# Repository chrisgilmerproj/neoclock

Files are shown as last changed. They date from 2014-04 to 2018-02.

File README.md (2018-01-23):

NeoClock
========

Neopixel clock based on neopixel rings from Adafruit.

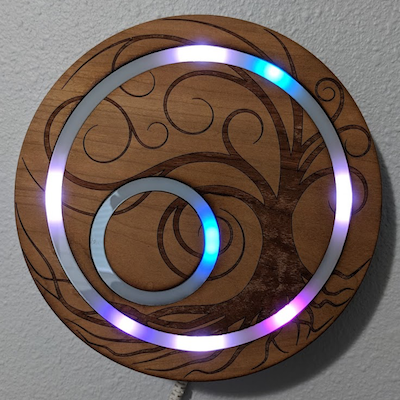
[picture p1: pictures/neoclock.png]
NeoClock


Code
---

The code can be found in the `./code/neoclock/neoclock.ino` file.

This project relies on code from several authors:

- https://github.com/adafruit/Adafruit_NeoPixel
- https://github.com/zeroeth/time_loop
- https://github.com/sparkfun/DeadOn_RTC

Some of the code is copied directly and some is only slightly modified.
Credit is due to the original authors who put in the work that allowed
me to build the clock.  Examples of code used are in the
`./code/examples/` directory.

Usage
---

The clock has two buttons for operation.  These are the Mode button and the
Set button.  The Mode button lets you choose between these choices:

1. Set Hour
2. Set Minute
3. Set Second
4. Set Color Scheme

The clock stops time while you set it allowing you to specify exactly the time
you want.  Finally you can choose one of four pre-programmed color sets for
the different hands of the clock.

Animations
---

Every fifteen minutes there is an animation sequence.  The top of the hour
runs a rainbow cycle.  The other three animations cycle one color through
all the pixels in the clock (Red, Green, Blue).

Laser Cut Files
---

The files used to laser cut the body of the clock are found in the `ponoko`
directory.  The final files sent to Ponoko were:

- `neoclock_ponoko_wood_final.eps`
- `neoclock_ponoko_acrylic_final.eps`

The original SVG files are provided for convenience.

The wood used was a `Veneer MDF Cherry 5.7mm` at 384mm square.

The acrylic used was an `Acrylic Opal 5.6mm` at 181mm square.

Electronics
---

The list of parts can be found in the `electronics` directory.

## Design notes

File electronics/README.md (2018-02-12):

# Electronics

This is a (mostly) complete list of parts used to make the electronics for the clock:

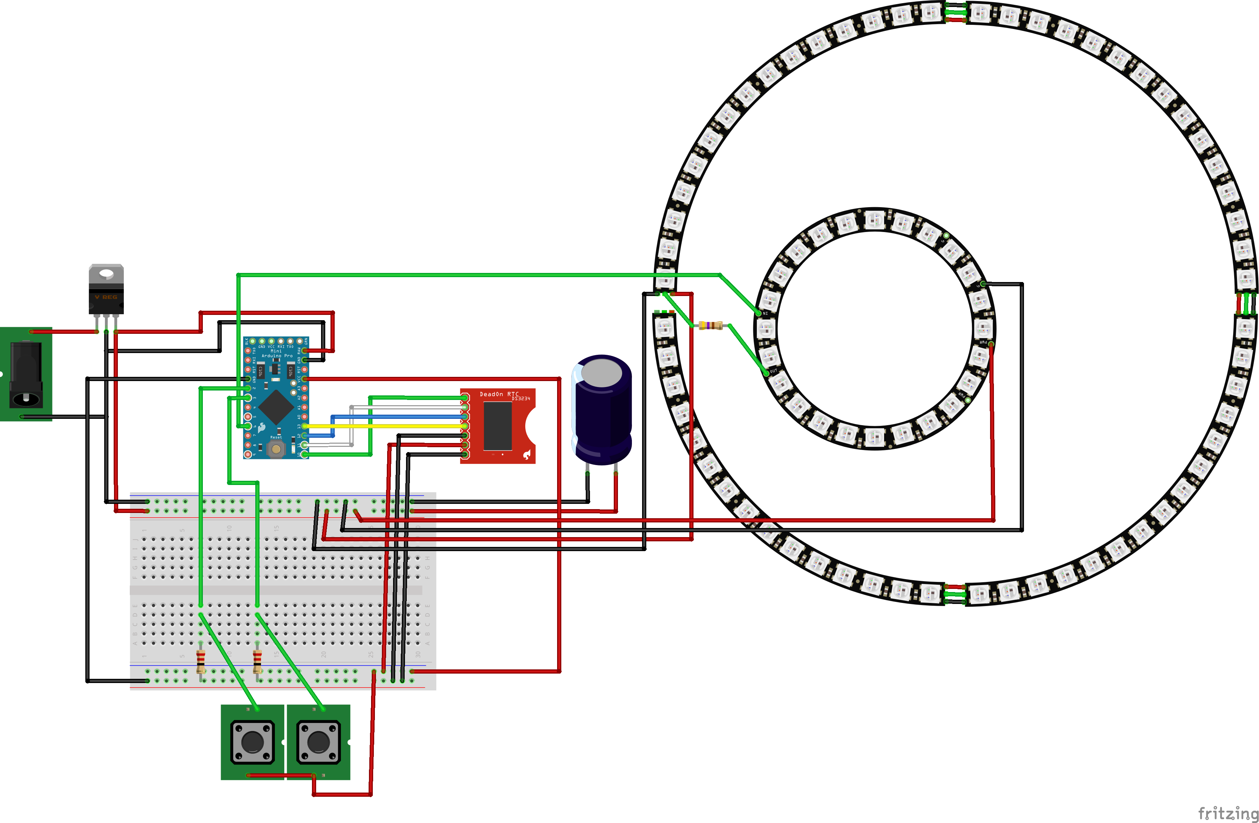
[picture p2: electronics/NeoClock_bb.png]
NeoClock


You can also open the [NeoClock Fritzing File](./NeoClock.fzz) to see how it was set up.

## SparkFun Parts

- 1x [DeadOn RTC Breakout - DS3234](https://www.sparkfun.com/products/10160) (BOB-10160)
- 1x [Coin Cell Battery 12mm CR1225](https://www.sparkfun.com/products/337) (PRT-00337)
- 1x [Arduino Mini 328 - 5V/16MHz](https://www.sparkfun.com/products/11113) (DEV-11113)
- 1x [L7805 Voltage Regulator 5V 1.5A-Max](https://www.sparkfun.com/products/107) (COM-00107)
- Resistors Avalable in [Resistor Kit 1/4W 500 Total](https://www.sparkfun.com/products/10969) (COM-10960)
  - 1x 470 Ohm 1/4W Resistor (yellow, violet, brown, silver)
  - 2x 1 kOhm 1/4W Resistor (brown, black, red, gold) (doesn't have to be exact here, just small and not smaller than)
    - I used 2.21 Ohm 1/4W Resistor (red, red, brown, silver, gold) because I had it, but it is too small

Also needed for programming the Arduino:

- 1x [FTDI Cable 5V](https://www.sparkfun.com/products/9718) (DEV-09718)

Also some wire:

- 1x [Hook-Up Wire - Assortment](https://www.sparkfun.com/products/11367) (Solid Core, 22 AWG ROHS) (PRT-11367)
  - This project used Red, Black and Green primarily.  Secondary colors are Yellow, Blue, White.

## Adafruit Parts

- 1x [NeoPixel Ring - 24 x WS2812 5050 RGB LED with Integrated Drivers](https://www.adafruit.com/product/1586) (1586)
- 4x [NeoPixel 1/4 60 Ring - 5050 RGB LED w/ Integrated Drivers](https://www.adafruit.com/product/1768) (1768)

## Radio Shack Parts

- 12V 1.5A Power Supply (Amperage is important here! Probably needs a min of 1A)
- 1x [1000uF Electrolytic Capacitor](https://www.radioshack.com/products/radioshack-1000uf-35v-20-axial-lead-electrolytic-capacitor) (Axial Leads, 35WVDC max) (272-1019)
- 2x [SPST Momentary Pushbutton Switch](https://www.radioshack.com/products/spst-pushbtn-swch) Contacts (N.O.) rated 3A at 125VAC or 1.5A at 250VAC (275-0644)
- 1x [Size K Coaxial DC Power Jack with Switch](https://www.radioshack.com/products/radioshack-size-k-coaxial-dc-power-jack-w-switch) (N.C. break circuit, 5.0mm OD, 2.1mm ID, with mounting hardware) (274-1565)
- 1x Mixed Round circuit boards
  - 1x 30mm in diameter
  - 1x 25mm in diameter
  - 1x 15mm in diameter

## Home Depot Parts

- 1x [Super Magnets, 12 Neodymium Ring Magnets](https://www.homedepot.com/p/MASTER-MAGNETICS-3-8-in-Neodymium-Rare-Earth-Magnet-Discs-12-per-Pack-07090HD/202526371) (095421070909)
- 1x [Gorilla Wood Glue](https://www.homedepot.com/p/Gorilla-8-fl-oz-Wood-Glue-62000/100672167) (052427620002)
- 1x [3/8 in x 4 ft wood round dowel](https://www.homedepot.com/p/3-8-in-x-48-in-Wood-Round-Dowel-HDDH3848/204354371)

## Other Parts

- Heat Shrink Tubing
- Quick Disconnects for wires

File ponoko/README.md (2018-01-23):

# Ponoko Files

These files were used to laser cut the clock body.  Here is a preview of the file:

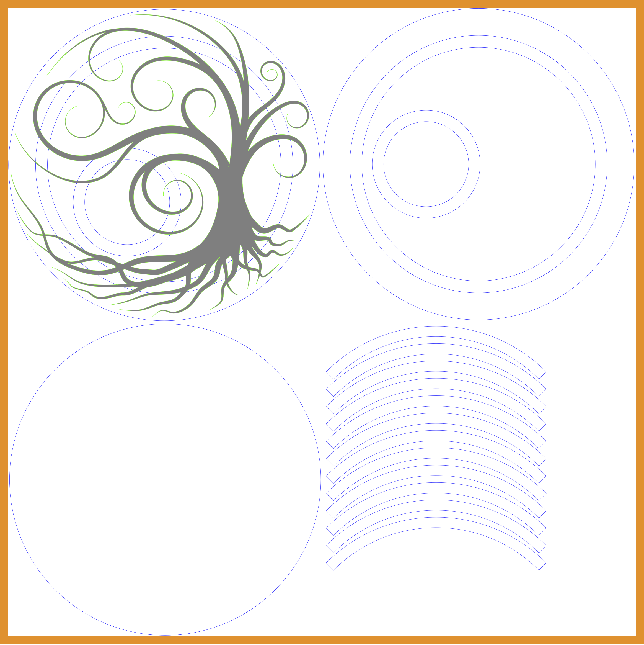
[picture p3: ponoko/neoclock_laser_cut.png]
NeoClock Body


**NOTE:** Only the `*.eps` files were sent to Ponoko.

All files were created using [Inkscape](https://inkscape.org/en/).

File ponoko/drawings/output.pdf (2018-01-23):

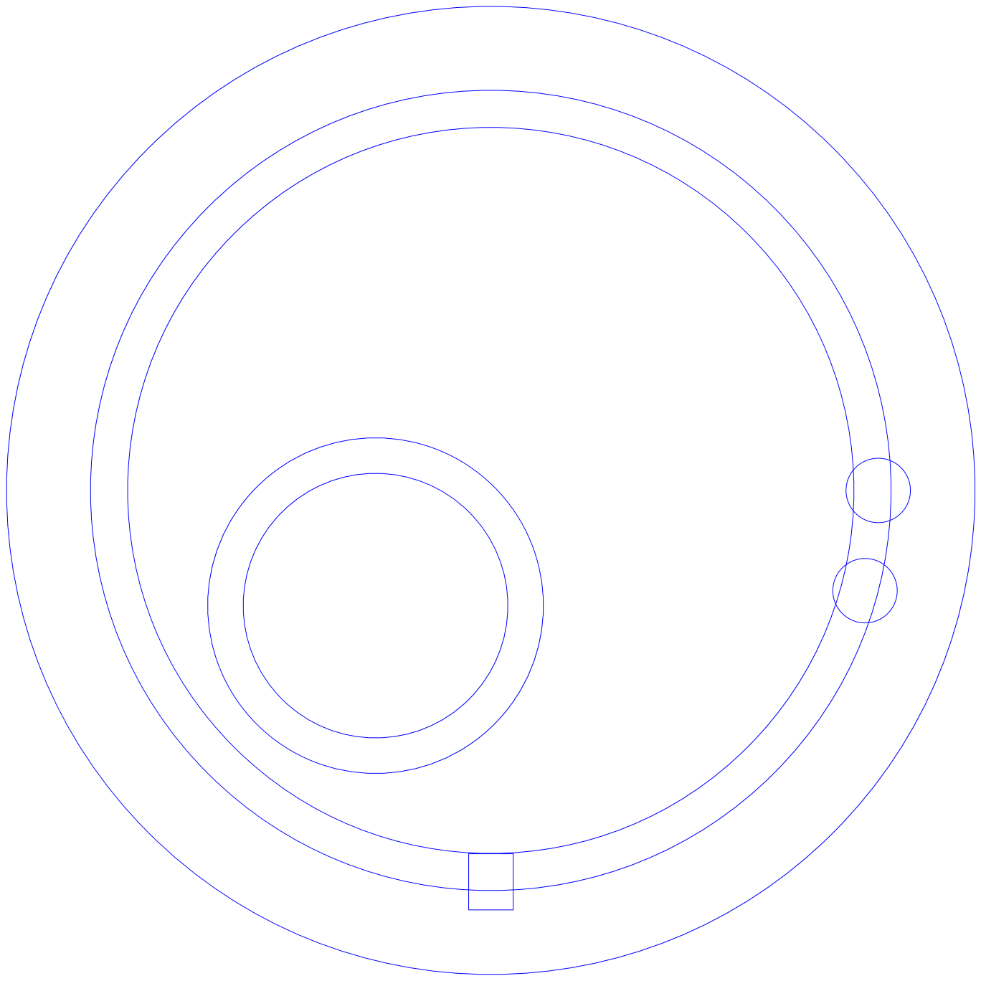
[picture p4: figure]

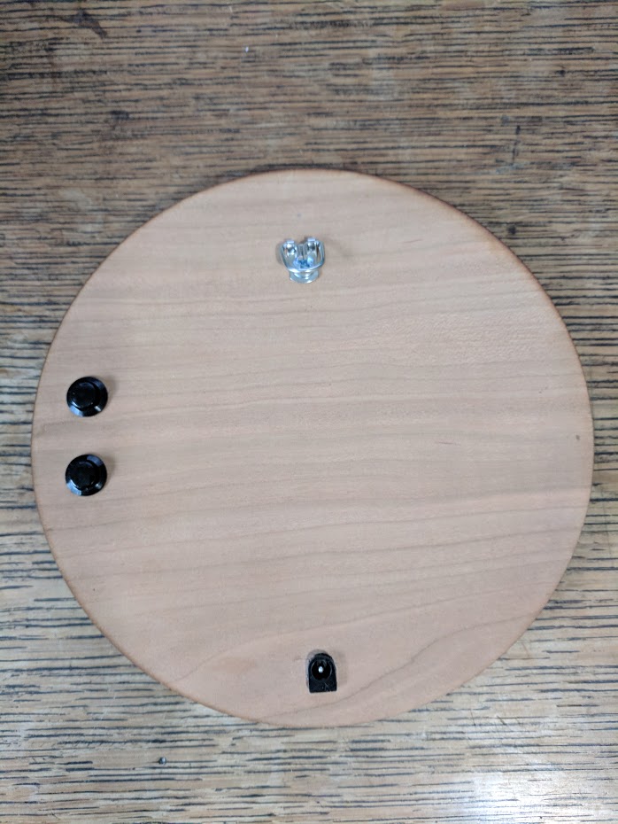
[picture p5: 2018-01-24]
pictures/neoclock_back.jpg

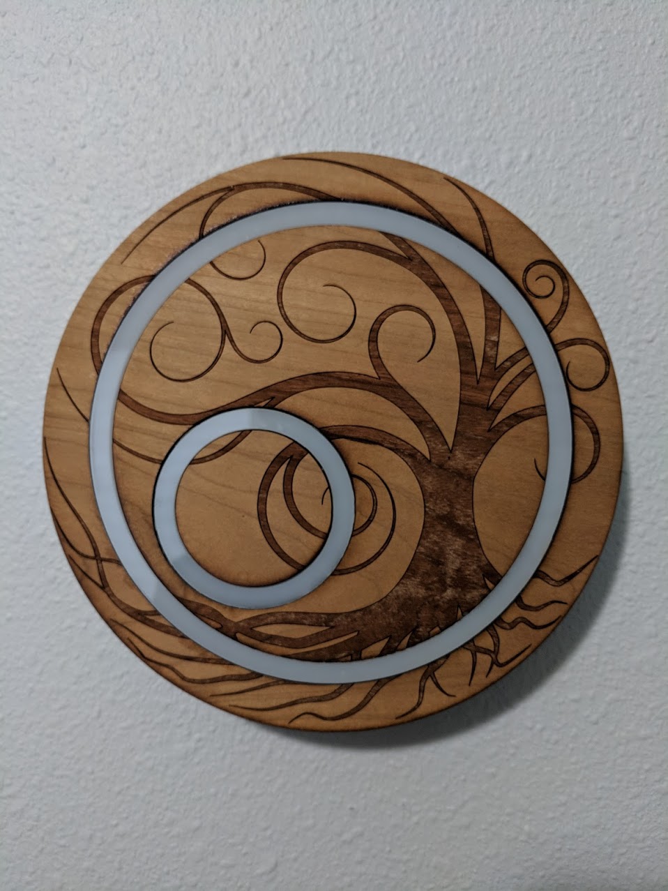
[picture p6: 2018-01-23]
pictures/neoclock_off.jpg

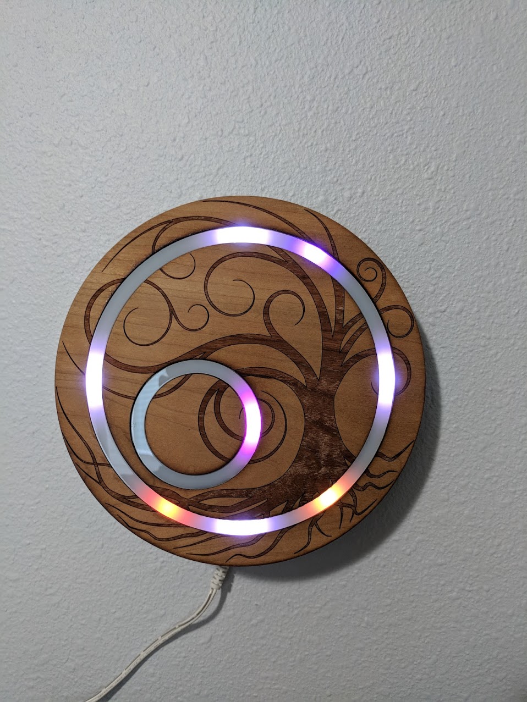
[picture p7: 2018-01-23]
pictures/neoclock_color_scheme_2.jpg

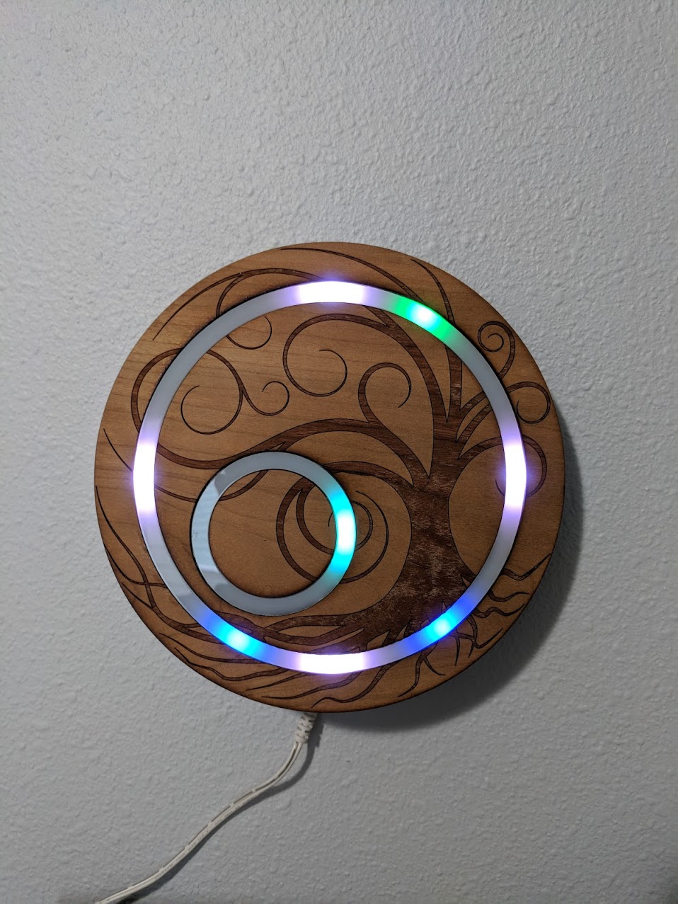
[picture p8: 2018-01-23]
pictures/neoclock_color_scheme_3.jpg

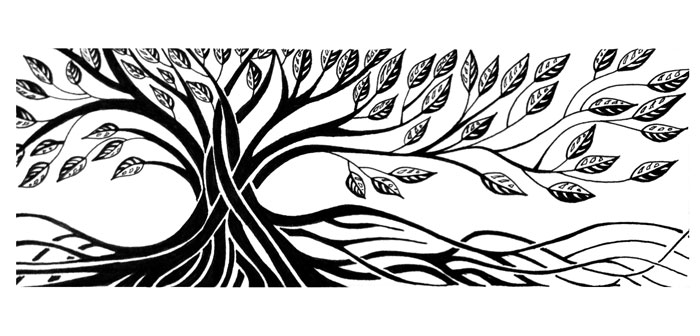
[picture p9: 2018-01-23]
ponoko/tree_research/zana_tree-of-life.jpg

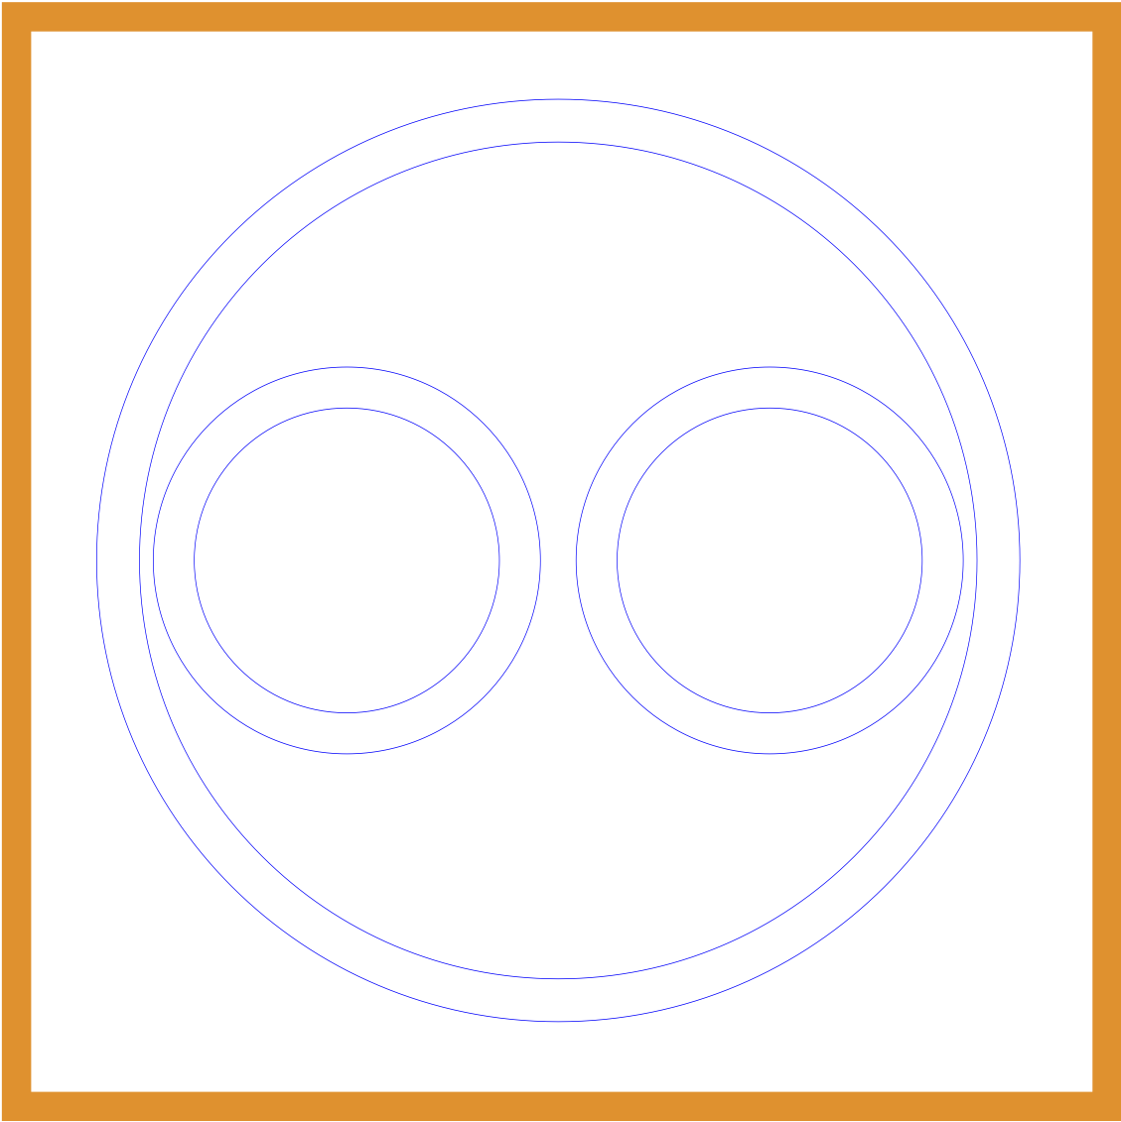
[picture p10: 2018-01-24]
ponoko/neoclock_laser_cut_acrylic.png

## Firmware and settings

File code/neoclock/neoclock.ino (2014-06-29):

// modified  https://github.com/zeroeth/time_loop
// modified  https://github.com/sparkfun/DeadOn_RTC
#include <Adafruit_NeoPixel.h>
#include <SPI.h>

#define SET_CLOCK_PIN 2
#define SET_TIME_PIN 3
#define RING_PIN 6
#define SLAVE_SELECT 10 // slave select rtc

// Set Clock Button
int clock_state;
int last_clock_state = LOW;

// Set Time Button
int time_state;
int last_time_state = LOW;

// Track Clock Set States
int num_states = 5;       // Number of clock states:
int clock_time_state = 0; // 0 - Run Clock
                          // 1 - Set Hour
                          // 2 - Set Minute
                          // 3 - Set Second
                          // 4 - Set Colors

// Debounce buttons
long last_clock_debounce_time = 0;
long last_time_debounce_time = 0;
long debounce_delay = 50; // milliseconds

// From adaFruit NEOPIXEL goggles example: Gamma correction improves appearance of midrange colors
const uint8_t gamma[] = {
      0,  0,  0,  0,  0,  0,  0,  0,  0,  0,  0,  0,  0,  0,  0,  0,
      0,  0,  0,  0,  0,  0,  0,  0,  1,  1,  1,  1,  1,  1,  1,  1,
      1,  1,  1,  1,  2,  2,  2,  2,  2,  2,  2,  2,  3,  3,  3,  3,
      3,  3,  4,  4,  4,  4,  5,  5,  5,  5,  5,  6,  6,  6,  6,  7,
      7,  7,  8,  8,  8,  9,  9,  9, 10, 10, 10, 11, 11, 11, 12, 12,
     13, 13, 13, 14, 14, 15, 15, 16, 16, 17, 17, 18, 18, 19, 19, 20,
     20, 21, 21, 22, 22, 23, 24, 24, 25, 25, 26, 27, 27, 28, 29, 29,
     30, 31, 31, 32, 33, 34, 34, 35, 36, 37, 38, 38, 39, 40, 41, 42,
     42, 43, 44, 45, 46, 47, 48, 49, 50, 51, 52, 53, 54, 55, 56, 57,
     58, 59, 60, 61, 62, 63, 64, 65, 66, 68, 69, 70, 71, 72, 73, 75,
     76, 77, 78, 80, 81, 82, 84, 85, 86, 88, 89, 90, 92, 93, 94, 96,
     97, 99,100,102,103,105,106,108,109,111,112,114,115,117,119,120,
    122,124,125,127,129,130,132,134,136,137,139,141,143,145,146,148,
    150,152,154,156,158,160,162,164,166,168,170,172,174,176,178,180,
    182,184,186,188,191,193,195,197,199,202,204,206,209,211,213,215,
    218,220,223,225,227,230,232,235,237,240,242,245,247,250,252,255
};

// Parameter 1 = number of pixels in strip
// Parameter 2 = pin number (most are valid)
// Parameter 3 = pixel type flags, add together as needed:
//   NEO_RGB     Pixels are wired for RGB bitstream
//   NEO_GRB     Pixels are wired for GRB bitstream
//   NEO_KHZ400  400 KHz bitstream (e.g. FLORA pixels)
//   NEO_KHZ800  800 KHz bitstream (e.g. High Density LED strip)
int inner_offset = 24;
int inner_pixels = 24;
int outer_pixels = 60;
int pixels = inner_pixels + outer_pixels;
Adafruit_NeoPixel strip = Adafruit_NeoPixel(pixels, RING_PIN, NEO_GRB + NEO_KHZ800);

//Set number of hours, should be 12 or 24
int num_hours = 12;

//Set the top pixel for each ring
int inner_top_led = 11 % inner_pixels;
int outer_top_led = 36 % outer_pixels;

// Off Color
uint32_t off_color    = strip.Color (  0,  0,  0);

//RGB
int current_clock_color = 0;
uint8_t current_brightness = 0;
uint32_t milli_color, second_color, minute_color, hour_color;
uint32_t point_color = strip.Color ( 64, 64, 64); // white

// Keep the current time
int current_second;
int current_minute;
int current_hour;

/* CLOCK */
class ClockPositions
{
 public:
  uint8_t px_milli;
  uint8_t px_second;
  uint8_t px_minute;
  uint8_t px_hour;

  ClockPositions ();
  void update    ();
};


ClockPositions::ClockPositions()
{
  px_milli = px_second = px_minute = px_hour = 0;
}

void ClockPositions::update()
{
  // Inner Loop
  // If px is greater than inner pixels must subtract inner pixels
  px_hour   = inner_top_led + map (current_hour % num_hours, 0,  num_hours, 0, inner_pixels);
  if (px_hour > inner_pixels) { px_hour = px_hour - inner_pixels; };

  // Outer Loop
  // If px is greater than total pixels must subtract outer pixels
  // Update the milliseconds only if clock isn't being set
  if (clock_time_state == 0) {
    px_milli  = outer_top_led + map ((millis() %  1000), 0,  1000, 0, outer_pixels);
    if (px_milli > pixels) { px_milli = px_milli - outer_pixels; };
  }

  px_second = outer_top_led + map (current_second % 60, 0, 60, 0, outer_pixels);
  if (px_second > pixels) { px_second = px_second - outer_pixels; };
  
  px_minute = outer_top_led + map (current_minute % 60, 0, 60, 0, outer_pixels);
  if (px_minute > pixels) { px_minute = px_minute - outer_pixels;};

  // Fade up to full brightness (above 255 causes roll over)
  if (current_brightness < 255) {
    current_brightness += 1;
    strip.setBrightness(current_brightness);
  }
}


/* CLOCK VIEW */

class ClockSegments
{
 public:
  ClockPositions    &positions;
  Adafruit_NeoPixel &strip;

  ClockSegments (Adafruit_NeoPixel&, ClockPositions&);
  void draw  ();
  void clear ();
  void add_color (uint8_t position, uint32_t color);
  uint32_t blend (uint32_t color1, uint32_t color2);
};


ClockSegments::ClockSegments (Adafruit_NeoPixel& n_strip, ClockPositions& n_positions): strip (n_strip), positions (n_positions)
{
}


void ClockSegments::draw()
{
  clear();

  // Clock Points
  uint8_t px_00 = inner_offset + outer_top_led + 0;
  if (px_00 > pixels) { px_00 = px_00 - outer_pixels;};
  add_color (px_00, point_color);

  uint8_t px_15 = inner_offset + outer_top_led + 15;
  if (px_15 > pixels) { px_15 = px_15 - outer_pixels;};
  add_color (px_15, point_color);

  uint8_t px_30 = inner_offset + outer_top_led + 30;
  if (px_30 > pixels) { px_30 = px_30 - outer_pixels;};
  add_color (px_30, point_color);

  uint8_t px_45 = inner_offset + outer_top_led + 45;
  if (px_45 > pixels) { px_45 = px_45 - outer_pixels;};
  add_color (px_45, point_color);

  // Inner Ring
  add_color ((positions.px_hour+0)              % inner_pixels, hour_color);
  add_color ((positions.px_hour+1)              % inner_pixels, hour_color);
  
  // Outer Ring
  add_color (inner_offset + positions.px_minute % outer_pixels, minute_color);
  add_color (inner_offset + positions.px_second % outer_pixels, second_color);
  add_color (inner_offset + positions.px_milli  % outer_pixels, milli_color);

  strip.show ();
}


void ClockSegments::add_color (uint8_t position, uint32_t color)
{
  uint32_t blended_color = blend (strip.getPixelColor (position), color);

  /* Gamma mapping */
  uint8_t r,b,g;

  r = (uint8_t)(blended_color >> 16),
  g = (uint8_t)(blended_color >>  8),
  b = (uint8_t)(blended_color >>  0);

  strip.setPixelColor (position, blended_color);
}


uint32_t ClockSegments::blend (uint32_t color1, uint32_t color2)
{
  uint8_t r1,g1,b1;
  uint8_t r2,g2,b2;
  uint8_t r3,g3,b3;

  r1 = (uint8_t)(color1 >> 16),
  g1 = (uint8_t)(color1 >>  8),
  b1 = (uint8_t)(color1 >>  0);

  r2 = (uint8_t)(color2 >> 16),
  g2 = (uint8_t)(color2 >>  8),
  b2 = (uint8_t)(color2 >>  0);

  return strip.Color (constrain (r1+r2, 0, 255),
                      constrain (g1+g2, 0, 255),
                      constrain (b1+b2, 0, 255));
}


void ClockSegments::clear ()
{
  for(uint16_t i=0; i<strip.numPixels (); i++) {
      strip.setPixelColor (i, off_color);
  }
}

/* Color Palettes */
// Use https://kuler.adobe.com/create/color-wheel
// Analagous color scheme with some spread
// Multiply all values by 0.17 to reduce brightness

void setColorPrimary ()
{
  // primary colors
  milli_color  = strip.Color (  0,  0, 42); // blue
  second_color = strip.Color (  0, 42,  0); // green
  minute_color = strip.Color ( 42,  0,  0); // red
  hour_color   = strip.Color ( 42, 42, 42); // white
}

void setColorRoyal ()
{
  //blue, green, & purple
  milli_color  = strip.Color ( 24,  0, 24); // magenta
  second_color = strip.Color ( 17,  0, 44); // purple
  hour_color   = strip.Color (  0, 10, 44); // royal blue
  minute_color = strip.Color (  0, 44, 10); // green
}

void setColorTequila ()
{
  //tequila sunrise color scheme
  milli_color  = strip.Color ( 44, 21,  0); // redest orange
  second_color = strip.Color ( 44, 30,  0); // slightly yellower
  hour_color   = strip.Color ( 44, 42,  0); // yellow
  minute_color = strip.Color ( 43,  0,  5); // red
}

void setColorRed ()
{
  // 255,0,0 center on red
  milli_color  = strip.Color ( 43, 22,  0); // orange
  second_color = strip.Color ( 39, 10,  0); // red orange
  hour_color   = strip.Color ( 39,  0, 35); // pink
  minute_color = strip.Color ( 24,  0, 43); // purple
}

void setColorOrange ()
{
  // 255,128,0 center on orange
  milli_color  = strip.Color ( 38, 34,  0); // yellow
  second_color = strip.Color ( 34, 24,  0); // orange
  hour_color   = strip.Color ( 34,  8,  0); // red orange
  minute_color = strip.Color ( 38,  0,  3); // red
}

void setColorCyan ()
{
  // 0,255,255 center on cyan
  milli_color  = strip.Color (  0,  2, 43); // bluew
  second_color = strip.Color (  0, 20, 39); // orange
  hour_color   = strip.Color (  0, 39, 19); // red orange
  minute_color = strip.Color (  1, 43,  0); // red
}

void setColorBlue ()
{
  // 0,0,255 center on blue
  milli_color  = strip.Color ( 36,  1, 38); // pink
  second_color = strip.Color ( 17,  1, 34); // purple blue
  hour_color   = strip.Color (  1, 16, 34); // other blue
  minute_color = strip.Color (  0, 34, 38); // light blue
}

/* Clock */
int RTC_init(){
    pinMode(SLAVE_SELECT,OUTPUT); // chip select
    // start the SPI library:
    SPI.begin();
    SPI.setBitOrder(MSBFIRST);
    SPI.setDataMode(SPI_MODE1); // both mode 1 & 3 should work
    //set control register
    digitalWrite(SLAVE_SELECT, LOW);
    SPI.transfer(0x8E);
    SPI.transfer(0x60); //60= disable Osciallator and Battery SQ wave @1hz, temp compensation, Alarms disabled
    digitalWrite(SLAVE_SELECT, HIGH);
    delay(10);
}

//=====================================
// Methods to set time
// Write Address List:
// 0x80 - Second
// 0x81 - Minute
// 0x82 - Hour
// 0x83 - Weekday
// 0x84 - Day
// 0x85 - Month
// 0x86 - Year
//=====================================

void setValue(int address, int val){
    // Convert the values to hex
    int b = val/10;   // 10's spot
    int a = val-b*10; //  1's spot

    // For hour
    if (address == 0x82) {
      if (b==2) {
          b=B00000010;
      }
      else if (b==1) {
          b=B00000001;
      }
    }

    // Write the hex value back
    int out_val = a+(b<<4);

    digitalWrite(SLAVE_SELECT, LOW);
    SPI.transfer(address);
    SPI.transfer(out_val);
    digitalWrite(SLAVE_SELECT, HIGH);
}

void setSecond(int val){
    int address = 0x80;
    setValue(address, val);
}

void setMinute(int val){
    int address = 0x81;
    setValue(address, val);
}

void setWeekday(int val){
    int address = 0x82;
    setValue(address, val);
}

void setHour(int val){
    int address = 0x82;
    setValue(address, val);
}

void setTime(int h, int mi, int s){
    setHour(h);
    setMinute(mi);
    setSecond(s);
}

//=====================================
// Methods to get time
// Read Address List:
// 0x00 - Second
// 0x01 - Minute
// 0x02 - Hour
// 0x03 - Weekday
// 0x04 - Day
// 0x05 - Month
// 0x06 - Year
//=====================================

unsigned int getValue(int address){
  digitalWrite(SLAVE_SELECT, LOW);
  SPI.transfer(address);
  unsigned int n = SPI.transfer(0x00);
  digitalWrite(SLAVE_SELECT, HIGH);
  return n;
}

int getSecond(){
  int address = 0x00;
  unsigned int n = getValue(address);
  int a = n & B00001111;
  int b = (n & B01110000)>>4;
  return a+b*10;
}

int getMinute(){
  int address = 0x01;
  unsigned int n = getValue(address);
  int a = n & B00001111;
  int b = (n & B01110000)>>4;
  return a+b*10;
}

int getHour(){
  int address = 0x02;
  unsigned int n = getValue(address);
  int a = n & B00001111;
  int b=(n & B00110000)>>4; //24 hour mode
  if(b==B00000010)
      b=20;
  else if(b==B00000001)
      b=10;
  return a + b;
}

/* APP */
ClockPositions positions;
ClockSegments  segments(strip, positions);

void setup ()
{
  // Initialize Buttons
  pinMode(SET_CLOCK_PIN, INPUT);
  pinMode(SET_TIME_PIN, INPUT);
  
  // Initialize the Clock
  Serial.begin(9600);
  RTC_init();

  setColorBlue();
  strip.begin ();
  strip.show (); // Initialize all pixels to 'off'
}


void loop ()
{
  // Change the clock settings state
  int clock_reading = digitalRead(SET_CLOCK_PIN);
  if (clock_reading != last_clock_state) {
    last_clock_debounce_time = millis();
  }
  if ((millis() - last_clock_debounce_time) > debounce_delay) {
    if (clock_reading != clock_state) {
      clock_state = clock_reading;

      // Change clock state on button press
      if (clock_state == HIGH) {
        clock_time_state = (clock_time_state + 1) % num_states;
      }
    }
  }
  last_clock_state = clock_reading;

  // Set the hours, minutes or seconds
  if (clock_time_state != 0) {
    int time_reading = digitalRead(SET_TIME_PIN);
    if (time_reading != last_time_state) {
      last_time_debounce_time = millis();
    }
    if ((millis() - last_time_debounce_time) > debounce_delay) {
      if (time_reading != time_state) {
        time_state = time_reading;

        if (time_state == HIGH) {
          if (clock_time_state == 1) {
            // Update Hours
            current_hour = (current_hour + 1) % 24;
          }
          else if (clock_time_state == 2) {
            // Update minutes
            current_minute = (current_minute + 1) % 60;
          }
          else if (clock_time_state == 3) {
            // Update seconds
            current_second = (current_second + 1) % 60;
          }
          else if (clock_time_state == 4) {
            current_clock_color = (current_clock_color + 1) % 4;
            if (current_clock_color == 0) {
              setColorBlue();
            }
            else if (current_clock_color == 1) {
              setColorRed();
            }
            else if (current_clock_color == 2) {
              setColorCyan();
            }
            else if (current_clock_color == 3) {
              setColorOrange();
            }
          }
        }
      }
    }
    // Set time
    setTime(current_hour, current_minute, current_second);
    last_time_state = time_reading;
  } 
  else {
    // Get Time only if not in setting mode
    current_second = getSecond();
    current_minute = getMinute();
    current_hour = getHour();
  }

  // Update positions
  positions.update();

  // Animations for 4 clock quarters
  if ((current_minute == 0) && (current_second == 0)) {
    rainbowMultiCycle(10);
  }
  else if ((current_minute == 15) && (current_second == 0)) {
    colorWipe(strip.Color(255, 0, 0), 25); // Red
  }
  else if ((current_minute == 30) && (current_second == 0)) {
    colorWipe(strip.Color(0, 255, 0), 25); // Green
  }
  else if ((current_minute == 45) && (current_second == 0)) {
    colorWipe(strip.Color(0, 0, 255), 25); // Blue
  }

  // Draw the clock
  segments.draw();
}


// Fill the dots one after the other with a color
void colorWipe(uint32_t c, uint32_t wait) {
  fadeOut();

  int num_pixels = strip.numPixels();
  for(uint16_t i=0; i<num_pixels; i++) {
    strip.setPixelColor(i, c);
    current_brightness += 255 / num_pixels;
    strip.setBrightness(current_brightness);
    strip.show();
    delay(wait);
  }
  fadeOut();
}

// Slightly different, this makes the rainbow equally distributed throughout
// across two rings
void rainbowMultiCycle(uint8_t wait) {
  uint16_t i, j, k;
  fadeOut();

  for(k=0; k<256; k++) { // cycles of all colors on wheel
    for(i=0; i< inner_pixels; i++) {
      strip.setPixelColor(i, Wheel(((i * 256 / inner_pixels) + k) & 255));
    }
    for(j=0; j< outer_pixels; j++) {
      strip.setPixelColor(inner_pixels + j, Wheel(((j * 256 / outer_pixels) + k) & 255));
    }
    current_brightness = k;
    strip.setBrightness(current_brightness);
    strip.show();
    delay(wait);
  }
  fadeOut();
}

void fadeOut()
{
  while (current_brightness != 0) {
    current_brightness -= 1;
    strip.setBrightness(current_brightness);
    strip.show();
    delay(1);
  }
}

// Input a value 0 to 255 to get a color value.
// The colours are a transition r - g - b - back to r.
uint32_t Wheel(byte WheelPos) {
  if(WheelPos < 85) {
   return strip.Color(WheelPos * 3, 255 - WheelPos * 3, 0);
  } else if(WheelPos < 170) {
   WheelPos -= 85;
   return strip.Color(255 - WheelPos * 3, 0, WheelPos * 3);
  } else {
   WheelPos -= 170;
   return strip.Color(0, WheelPos * 3, 255 - WheelPos * 3);
  }
}

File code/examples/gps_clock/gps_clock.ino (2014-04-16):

//NeoPixel clock with FLORA based on Kevin Alford's NeoPixel ring clock face
//https://github.com/zeroeth/time_loop
//http://www.youtube.com/watch?v=b-mROp-ZKuk
//modified by Becky Stern for Adafruit Industries
#include <Adafruit_NeoPixel.h>
#include <Time.h>
#include <Adafruit_GPS.h>
#include <SoftwareSerial.h>
#include <Wire.h>

Adafruit_GPS GPS(&Serial1);

#define PIN 12

// Set GPSECHO to 'false' to turn off echoing the GPS data to the Serial console
// Set to 'true' if you want to debug and listen to the raw GPS sentences
#define GPSECHO false
     
// this keeps track of whether we're using the interrupt
// off by default!
boolean usingInterrupt = false;

// From adaFruit NEOPIXEL goggles example: Gamma correction improves appearance of midrange colors
const uint8_t gamma[] = {
      0,  0,  0,  0,  0,  0,  0,  0,  0,  0,  0,  0,  0,  0,  0,  0,
      0,  0,  0,  0,  0,  0,  0,  0,  1,  1,  1,  1,  1,  1,  1,  1,
      1,  1,  1,  1,  2,  2,  2,  2,  2,  2,  2,  2,  3,  3,  3,  3,
      3,  3,  4,  4,  4,  4,  5,  5,  5,  5,  5,  6,  6,  6,  6,  7,
      7,  7,  8,  8,  8,  9,  9,  9, 10, 10, 10, 11, 11, 11, 12, 12,
     13, 13, 13, 14, 14, 15, 15, 16, 16, 17, 17, 18, 18, 19, 19, 20,
     20, 21, 21, 22, 22, 23, 24, 24, 25, 25, 26, 27, 27, 28, 29, 29,
     30, 31, 31, 32, 33, 34, 34, 35, 36, 37, 38, 38, 39, 40, 41, 42,
     42, 43, 44, 45, 46, 47, 48, 49, 50, 51, 52, 53, 54, 55, 56, 57,
     58, 59, 60, 61, 62, 63, 64, 65, 66, 68, 69, 70, 71, 72, 73, 75,
     76, 77, 78, 80, 81, 82, 84, 85, 86, 88, 89, 90, 92, 93, 94, 96,
     97, 99,100,102,103,105,106,108,109,111,112,114,115,117,119,120,
    122,124,125,127,129,130,132,134,136,137,139,141,143,145,146,148,
    150,152,154,156,158,160,162,164,166,168,170,172,174,176,178,180,
    182,184,186,188,191,193,195,197,199,202,204,206,209,211,213,215,
    218,220,223,225,227,230,232,235,237,240,242,245,247,250,252,255
};

// Parameter 1 = number of pixels in strip
// Parameter 2 = pin number (most are valid)
// Parameter 3 = pixel type flags, add together as needed:
//   NEO_RGB     Pixels are wired for RGB bitstream
//   NEO_GRB     Pixels are wired for GRB bitstream
//   NEO_KHZ400  400 KHz bitstream (e.g. FLORA pixels)
//   NEO_KHZ800  800 KHz bitstream (e.g. High Density LED strip)
Adafruit_NeoPixel strip = Adafruit_NeoPixel(36, PIN, NEO_GRB + NEO_KHZ800);

//--------------------------------------------------|
//Your NeoPixel rings may not line up with ours, or each other.     |
//Enter which NeoPixel leds are on top LED (0-23 and 0-13).  |
  #define outerTOP_LED                10
  #define innerTOP_LED                5
//--------------------------------------------------|

int outertopLED = outerTOP_LED;
int innertopLED = innerTOP_LED;
float fLat = 0.0;
float fLon = 0.0;

//tequila sunrise color scheme

uint32_t milli_color  = strip.Color ( 44,  21,  0); // redest orange
uint32_t second_color = strip.Color (  44,  30, 0); //slightly yellower
uint32_t hour_color   = strip.Color (  44, 42,  0); //yellow
uint32_t minute_color = strip.Color ( 43, 0, 5); //red
uint32_t off_color    = strip.Color (  0,  0,  0);


//blue, green, & purple color scheme
/*
uint32_t milli_color  = strip.Color ( 24,  0,  24); // magenta
uint32_t second_color = strip.Color (  17,  0, 44); // purple
uint32_t hour_color   = strip.Color (  0, 10,  44); // royal blue
uint32_t minute_color = strip.Color ( 0, 44, 10); // green
uint32_t off_color    = strip.Color (  0,  0,  0);
*/

// Offset hours from gps time (UTC)
//const int offset = 1;   // Central European Time
const int offset = -4;  // Eastern Daylight Time (USA)
//const int offset = -5;  // Central Daylight Time (USA)
//const int offset = -8;  // Pacific Standard Time (USA)
//const int offset = -7;  // Pacific Daylight Time (USA)

/* CLOCK */
class ClockPositions
{
 public:
 
  uint8_t milli;
  uint8_t currentsecond;
  uint8_t currentminute;
  uint8_t currenthour;


  ClockPositions ();
  void update    ();
};


ClockPositions::ClockPositions()
{
  /*
  milli = 0;
  second = 0;
  minute = 30;
  hour = 6;
  */
  //DateTime(__DATE__, __TIME__);
  
}


void ClockPositions::update()
{
  
  if (GPS.fix) {
      // set the Time to the latest GPS reading
      setTime(GPS.hour, GPS.minute, GPS.seconds, GPS.day, GPS.month, GPS.year);
      delay(50);
      adjustTime(offset * SECS_PER_HOUR);
      
      delay(100);
    }
    
  currentsecond = outertopLED + map ((second() % 60), 0, 60, 0, 23);
  if (currentsecond > 24) {currentsecond = currentsecond-24;};
  milli  = map ((millis() %  1000), 0,  1000, 0, 24);
  currenthour   = innertopLED + map ((hour() % 12), 0,  12, 24, 35);
  if (currenthour > 35) { currenthour = currenthour-12;}
  //Serial.print("the hour is: ");
  //Serial.println(hour());
  currentminute = outertopLED + map (minute() % 60, 0,  60, 0, 23);
  if (currentminute > 23) {currentminute = currentminute-24;};
  //Serial.print("the minute is: ");
  //Serial.println(minute());
}



/* CLOCK VIEW */

class ClockSegments
{
 public:
  ClockPositions    &positions;
  Adafruit_NeoPixel &strip;

  ClockSegments (Adafruit_NeoPixel&, ClockPositions&);
  void draw  ();
  void clear ();
  void add_color (uint8_t position, uint32_t color);
  uint32_t blend (uint32_t color1, uint32_t color2);
};


ClockSegments::ClockSegments (Adafruit_NeoPixel& n_strip, ClockPositions& n_positions): strip (n_strip), positions (n_positions)
{
}


void ClockSegments::draw()
{
  clear();

  add_color (positions.currentminute,  minute_color);
  //Serial.println(positions.minute);
  add_color (positions.currenthour,  hour_color  );


  add_color (positions.currentsecond     % 24, second_color);
  add_color ((positions.currentsecond+1) % 24, second_color);
  //add_color ((positions.second+2) % 24, second_color);

/*
  add_color (positions.milli     % 24,  milli_color);
  add_color ((positions.milli+1) % 24,  milli_color);
  add_color ((positions.milli+2) % 24,  milli_color);
*/
  strip.show ();
}


void ClockSegments::add_color (uint8_t position, uint32_t color)
{
  uint32_t blended_color = blend (strip.getPixelColor (position), color);

  /* Gamma mapping */
  uint8_t r,b,g;

  r = (uint8_t)(blended_color >> 16),
  g = (uint8_t)(blended_color >>  8),
  b = (uint8_t)(blended_color >>  0);

  strip.setPixelColor (position, blended_color);
}


uint32_t ClockSegments::blend (uint32_t color1, uint32_t color2)
{
  uint8_t r1,g1,b1;
  uint8_t r2,g2,b2;
  uint8_t r3,g3,b3;

  r1 = (uint8_t)(color1 >> 16),
  g1 = (uint8_t)(color1 >>  8),
  b1 = (uint8_t)(color1 >>  0);

  r2 = (uint8_t)(color2 >> 16),
  g2 = (uint8_t)(color2 >>  8),
  b2 = (uint8_t)(color2 >>  0);


  return strip.Color (constrain (r1+r2, 0, 255), constrain (g1+g2, 0, 255), constrain (b1+b2, 0, 255));
}


void ClockSegments::clear ()
{
  for(uint16_t i=0; i<strip.numPixels (); i++) {
      strip.setPixelColor (i, off_color);
  }
}



/* SIMPLE MIXER */
// add rgb and clamp





/* APP */
ClockPositions positions;
ClockSegments  segments(strip, positions);
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

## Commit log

2014-04-19 Add back milliseconds
2014-06-07 Add ability to read from input buttons. Sets clock state. Needs time setting
2014-06-08 Set time methods work, added second setting, changed millisecond updating
2014-06-08 Fix milliseconds stop
2014-06-28 Change pin for chip select
2018-01-23 Add fritzing file and an image of the electronics connected together
    [NeoClock.fzz]
2018-01-23 Include a preview picture of the laser cutting
2018-01-24 Include power and ground wires to neopixels
    [NeoClock.fzz]
2018-02-12 Update the parts list for pull down resistors
